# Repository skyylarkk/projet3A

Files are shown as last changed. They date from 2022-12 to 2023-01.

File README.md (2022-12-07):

# Robot arm project

This project is carried out by a three-students group in option Mechatronics and Complex Systems at ENSEA.

### Objectives

Our project consists in the realization of a 6-axis robot capable of catching and maintaining without damaging it a pot of yogurt. This could help people with disabilities.

### Mecanics

The mechanical part of the robot is modelled using SolidWorks software and then printed in 3D. The corresponding folder in the repository lists the various elements of the robot and their associated SolidWorks files (parts + assembly).

### Power module

In order to make the robot work, we need to build a power module to distribute the right power to every parts of the robot. The robot is powered by alternative by 230 V at 50 Hz.

### Steppers code

We chose to command the steppers with a STM32 nucleo-G431RB card. We use the STM32CubeIDE software. The different code files for the command of these steppers are present in the corresponding folder in the repository.

## To start

Here are the different instructions instructions instructions to follow to make the project work :

### Requirements

In order to make the project work, you will need the following softwares :

- STM32CubeIDE
- SolidWorks
- a software to print in 3D
- a software for PCB modeling

You also need this equipement to build your robot :

- a 3D-printer
- a STM32 Nucleo-G431RB
- 3x stepper motors with at least a 4N tork 
- 2x AX-12
- 2x XL-320
- a power conversion module from 230 V to 24 V
- all the componants to make the PCB (you can see them in the PCB files)

## Starting

In the different folders of the repository you have access to the code for the steppers, the mecanical parts and the PCB scheme for the power module of the robot.

- for the steppers code, you need to use STM32CubeIDE to upload the code on your Nucleo. Be careful to use the code from the last stable version for this project.
- for the mecanical parts, you have acces to the files you can open with SolidWorks. It is useful if you want to modify the different part ase you want, but it can possibly impact the proper functioning of the robot. You also have access to STL files of every mecanical parts in order to print it in 3D.
- for the PCB, you have all the files needed to build it in order to make the robot work.

## Built/developped with

* [STM32CubeIDE](https://www.st.com/en/development-tools/stm32cubeide.html) - for the steppers code
* [SolidWorks](https://www.solidworks.com/) - for the mecanical parts

## Versions

**Last stable version :** 1.0
**Last version :** 1.0

## Autors

* **CHAPUIS Clément** _alias_ [@ClementChapuis](https://github.com/ClementChapuis)
* **HERAULT Félix** _alias_ [@FelixHerault](https://github.com/FelixHerault)
* **SUTRA Aurélien** _alias_ [@skyylarkk](https://github.com/skyylarkk)

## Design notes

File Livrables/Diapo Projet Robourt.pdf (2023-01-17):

# Réalisation d’un robot d’assistance pour les personnes en situation de handicap

## École Nationale Supérieure de l’Électronique et de ses Applications, Option Mécatronique et Systèmes Complexes

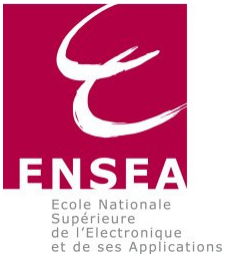
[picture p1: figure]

### Professeurs encadrants : Alexis MARTIN Nicolas PAPAZOGLOU

Année 2022 - 2023

Clément CHAPUIS, Félix HERAULT et Aurélien SUTRA Option MSC
Soutenance de projet

### 11 Janvier 2023

# Sommaire

### I - Contexte, objectifs et organisation du Projet 1 Contexte et objectifs 2 Diagramme de Gantt

### II - Le projet 1 Dimensionnement 2 Modélisation 3 Modèle réel 4 Commande des steppers

III - Conclusion | 2

3

# Contexte du projet

Contexte | Projet | Conclusion

Robot d'assistance

Mise en situation : préhension d'un pot de yaourt

Partenariat avec une clinique

Partage du travail avec un groupe d'étudiant en deuxième année

4

# Objectifs

Manipulation du pot de yaourt sans détérioration

Maintient de la position pendant l'alimentation du patient

Commande au fauteuil

Mémorisation de la position ?

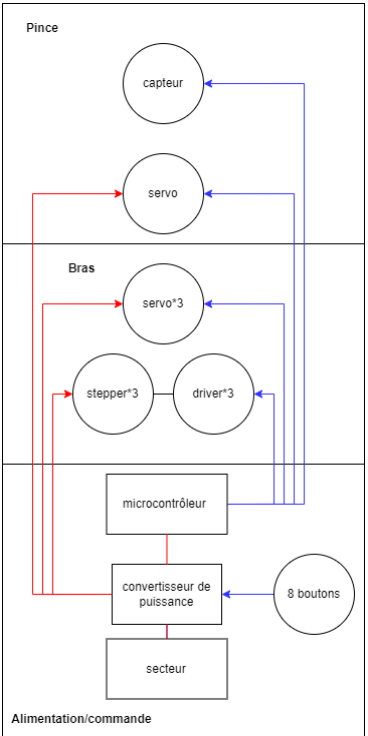
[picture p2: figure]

5

# Solution retenue

Robot 6 axes anthropomorphe avec différents modèles de pinces

Réduit à 3 axes avec une pince simple au fil du projet

# Digramme de Gantt

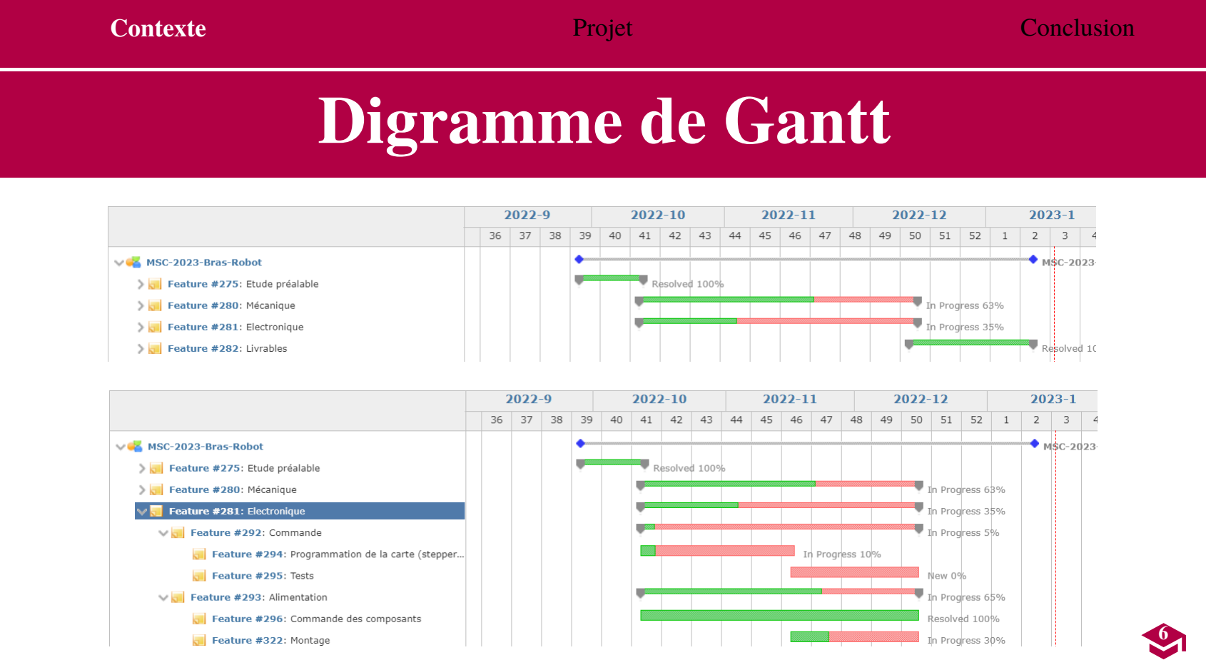
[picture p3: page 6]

6

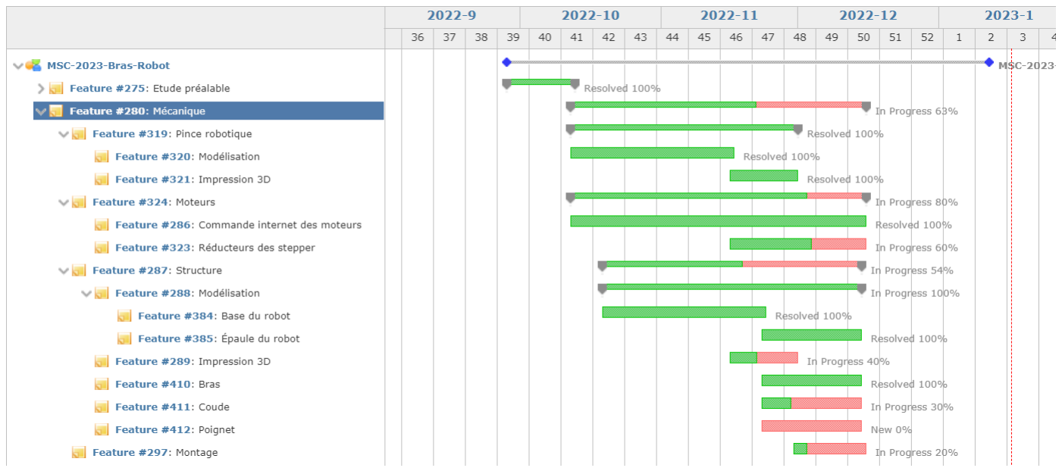
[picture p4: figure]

7

# Digramme de Gantt

# Architecture générale

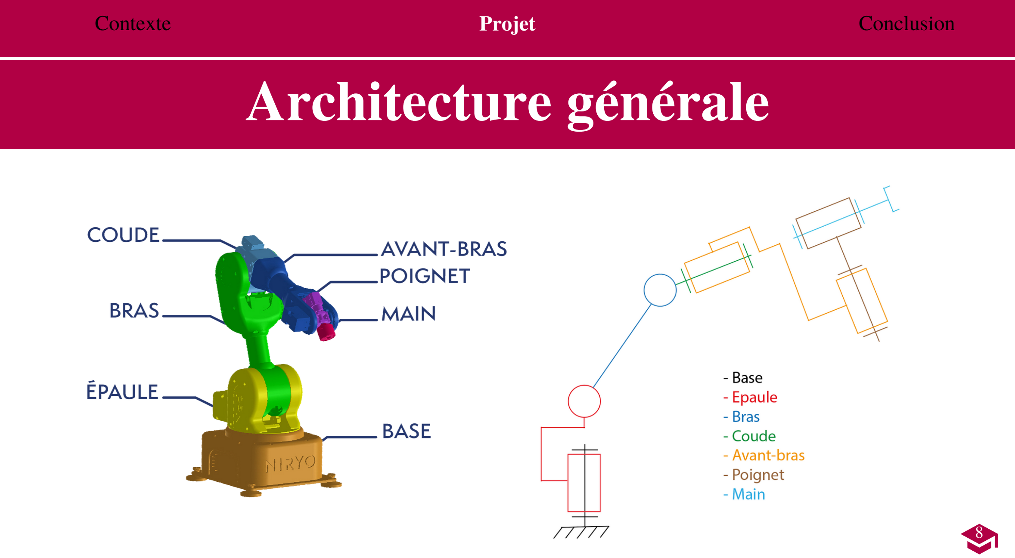
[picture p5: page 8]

8

# Dimensionnement

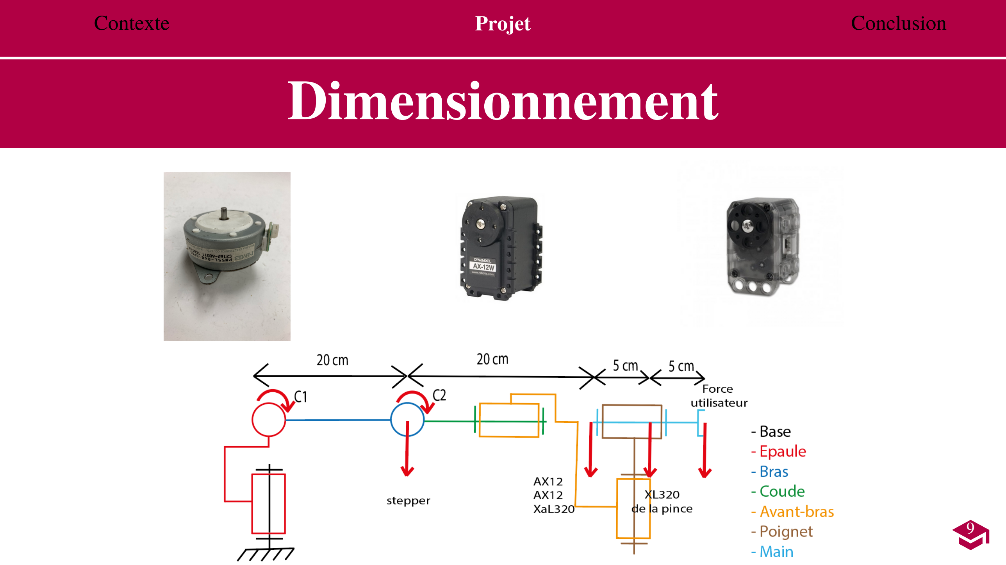
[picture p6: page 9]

9

# Modélisation - Base

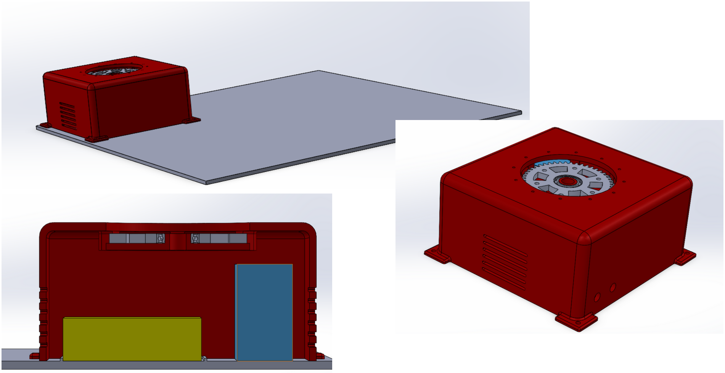
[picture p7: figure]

10

# Modélisation - Base

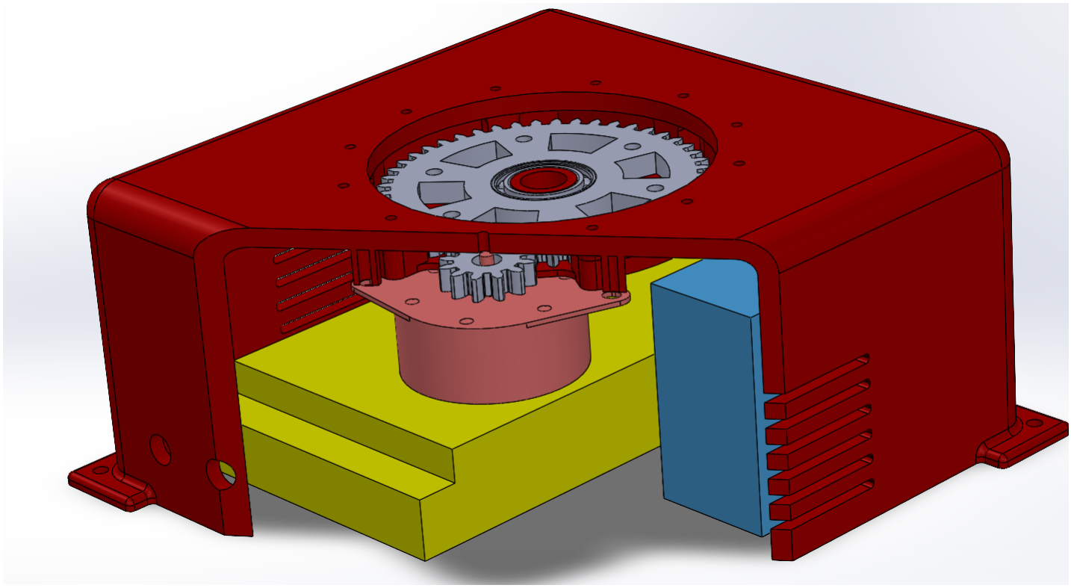
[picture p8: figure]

11

# Modélisation - Epaule

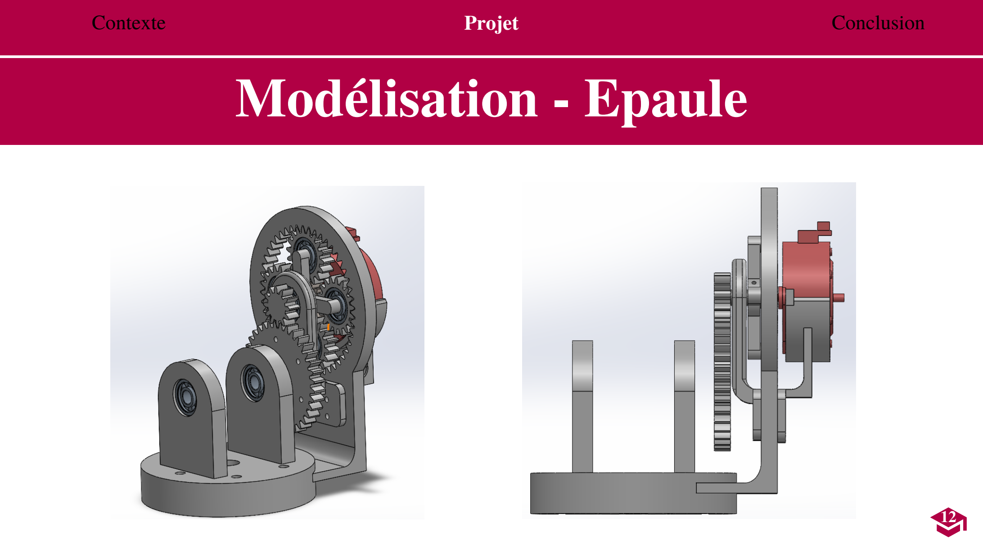
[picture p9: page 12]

12

# Modélisation - Epaule

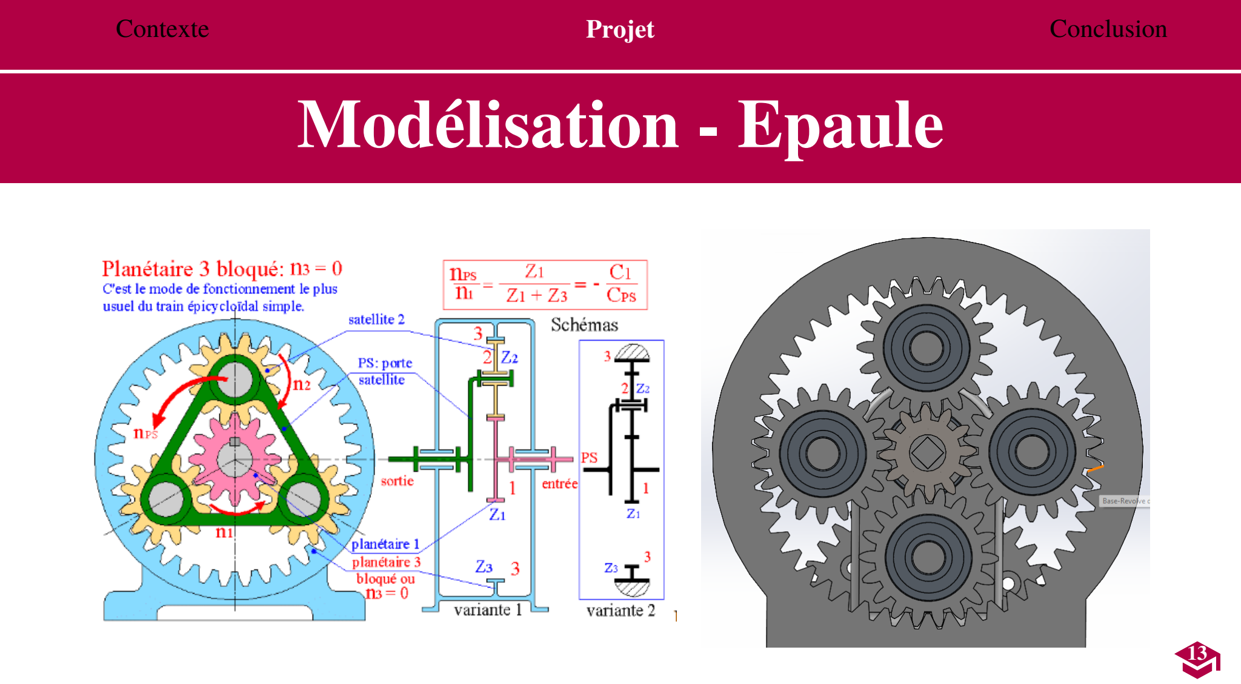
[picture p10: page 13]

13

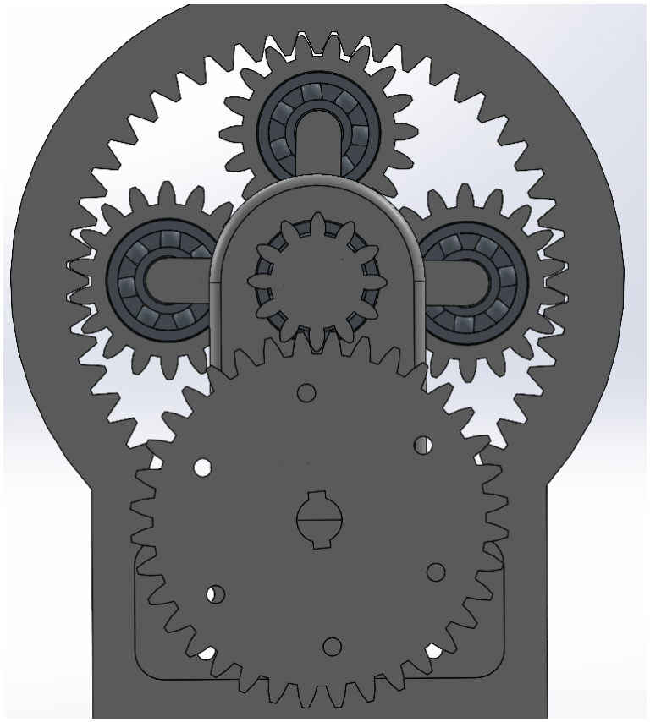
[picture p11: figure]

14

# Modélisation - Epaule

# Modélisation - Epaule + Bras

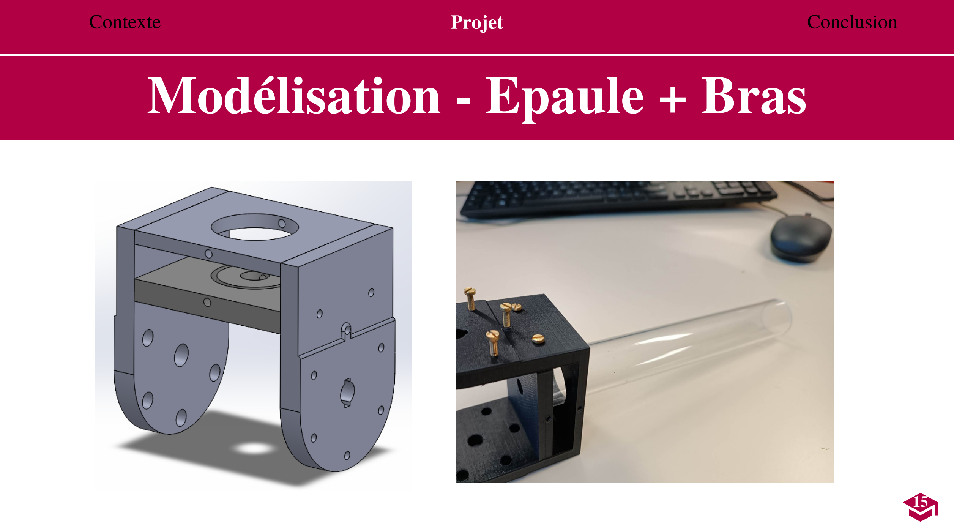
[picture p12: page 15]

15

# Modélisation

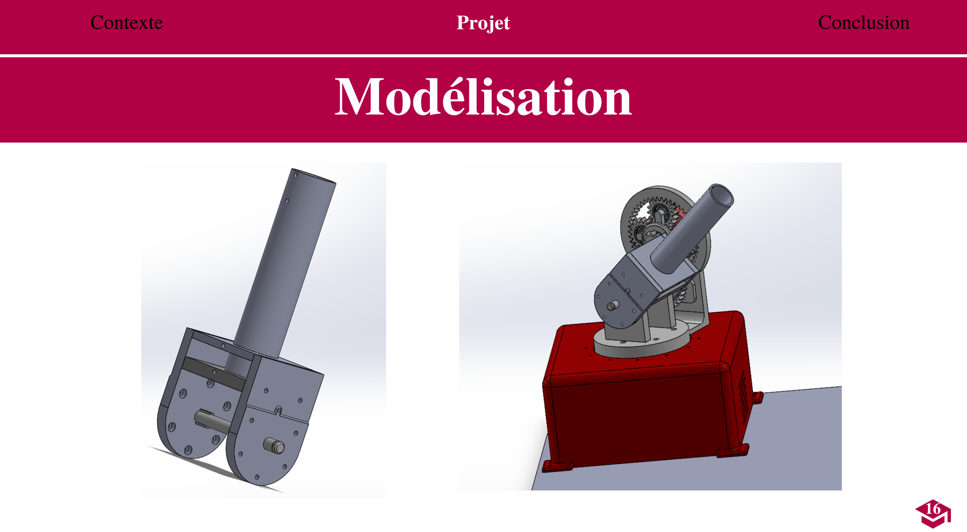
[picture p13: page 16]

16

# Modélisation - Pince

17

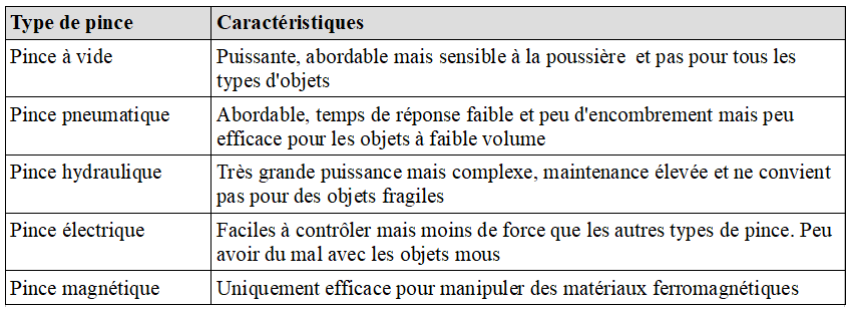
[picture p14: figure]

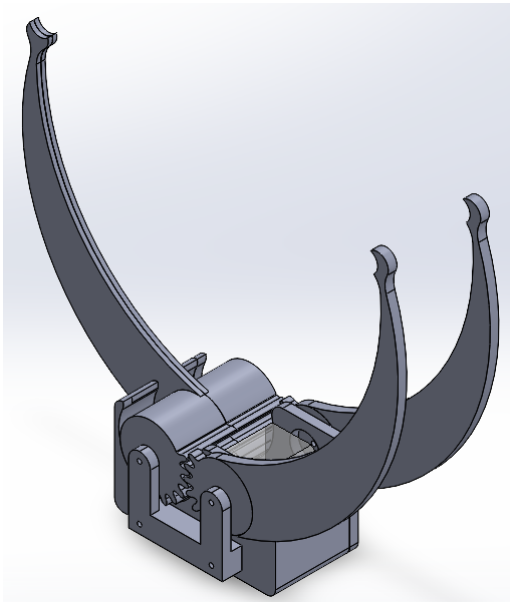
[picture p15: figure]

18

# Modélisation - Pince

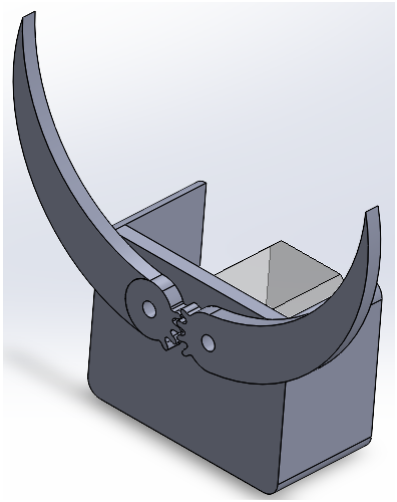
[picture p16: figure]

# Modèle réel

# Place à la démonstration

19

# Commande des steppers

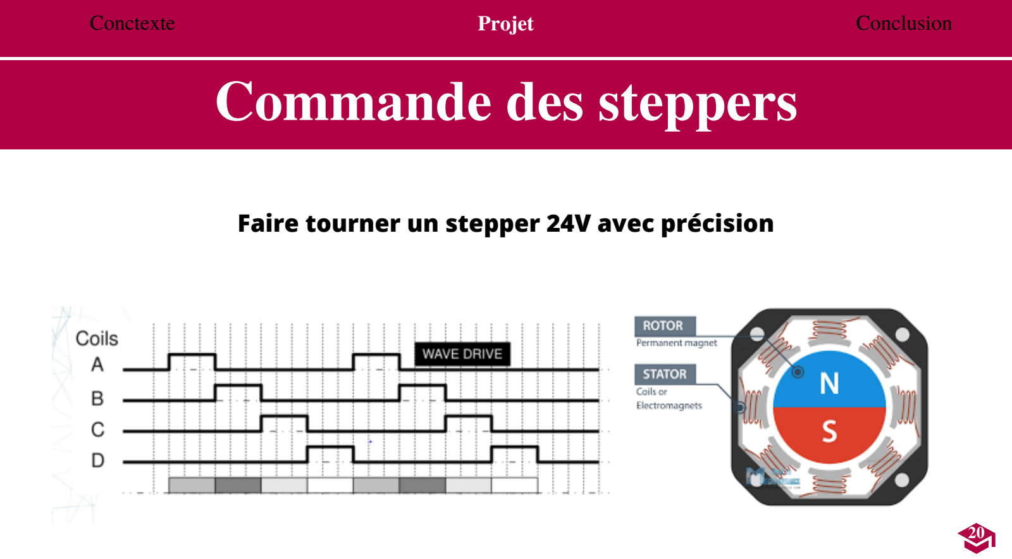
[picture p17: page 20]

Conctexte | Projet | Conclusion

Faire tourner un stepper 24V avec précision

20

# Commande des steppers

Conctexte | Projet | Conclusion

Solution : microstepping avec le driver TMC2225

4, 8, 16 ou 32 microsteps

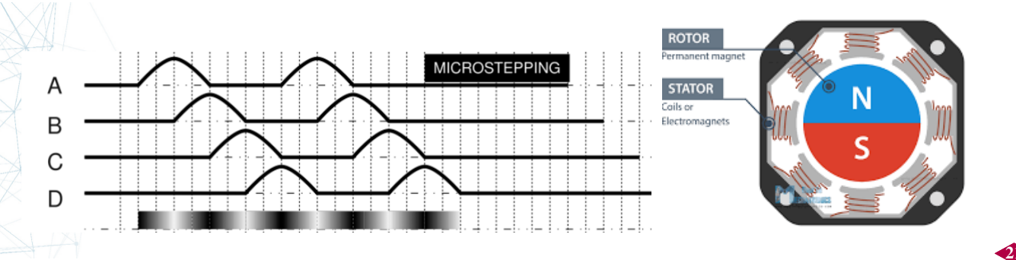
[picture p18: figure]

21

# TMC2225

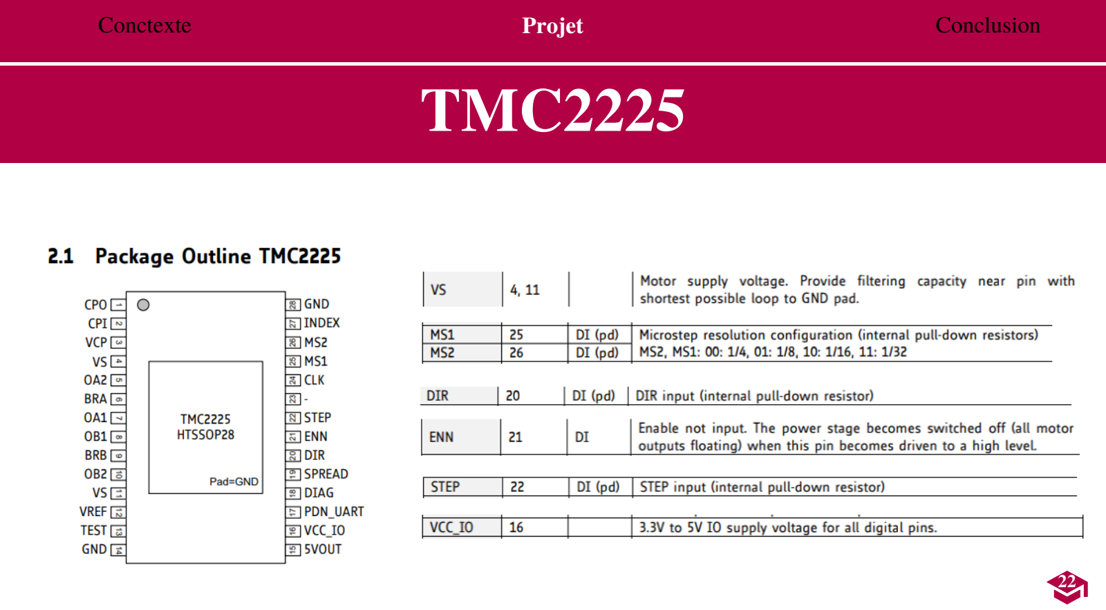
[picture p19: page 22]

Conctexte | Projet | Conclusion

22

# Buck

Conctexte | Projet | Conclusion

Convertit le 24V en 5V

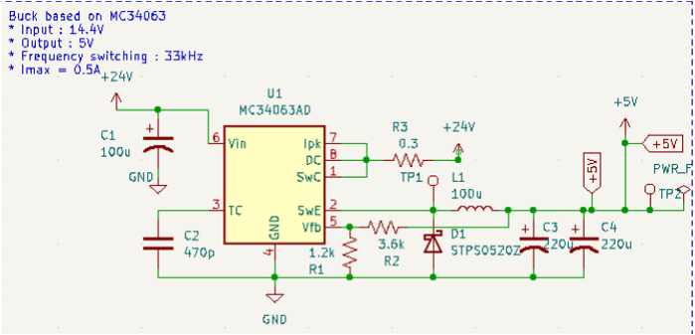
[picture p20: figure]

23

# Liaison entre les composants

Conctexte | Projet | Conclusion

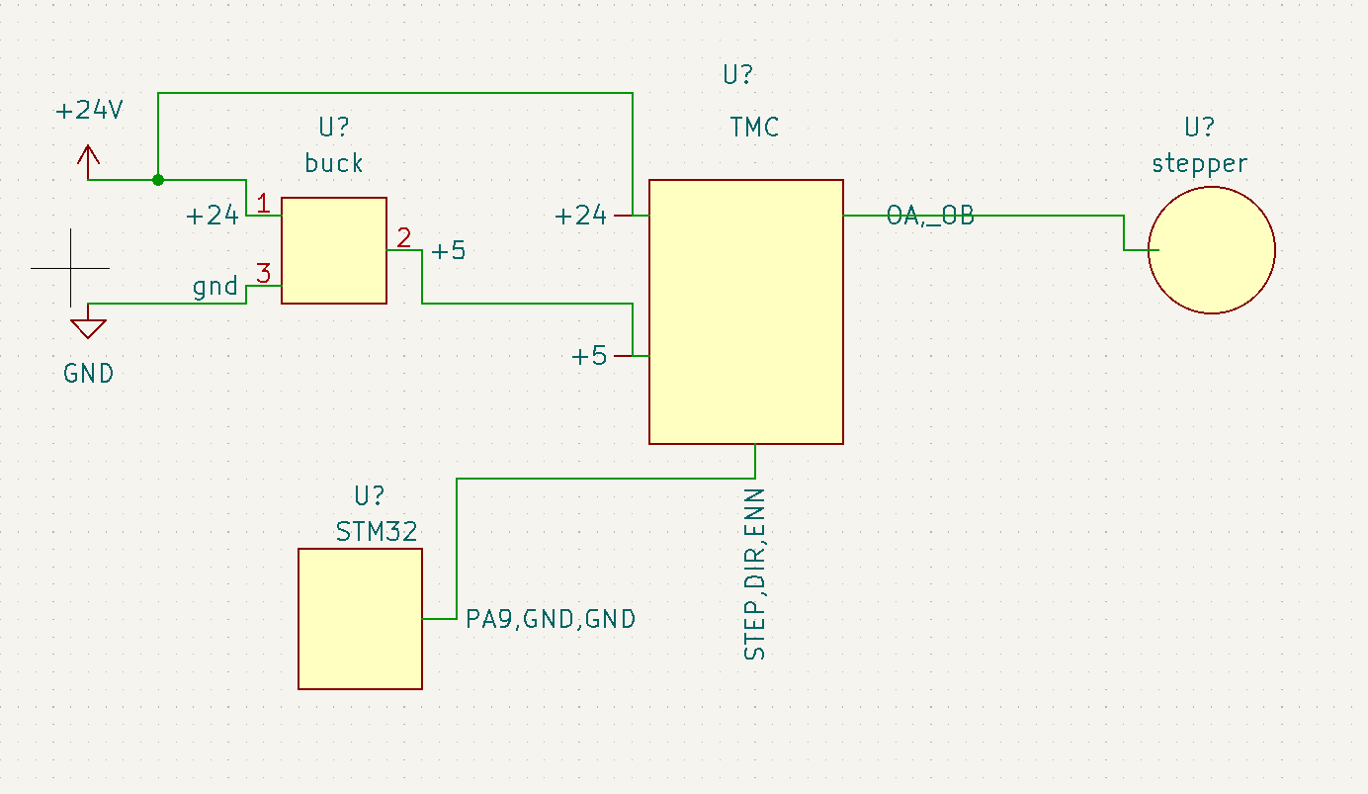
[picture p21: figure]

24

# Création du PCB

Conctexte | Projet | Conclusion

25

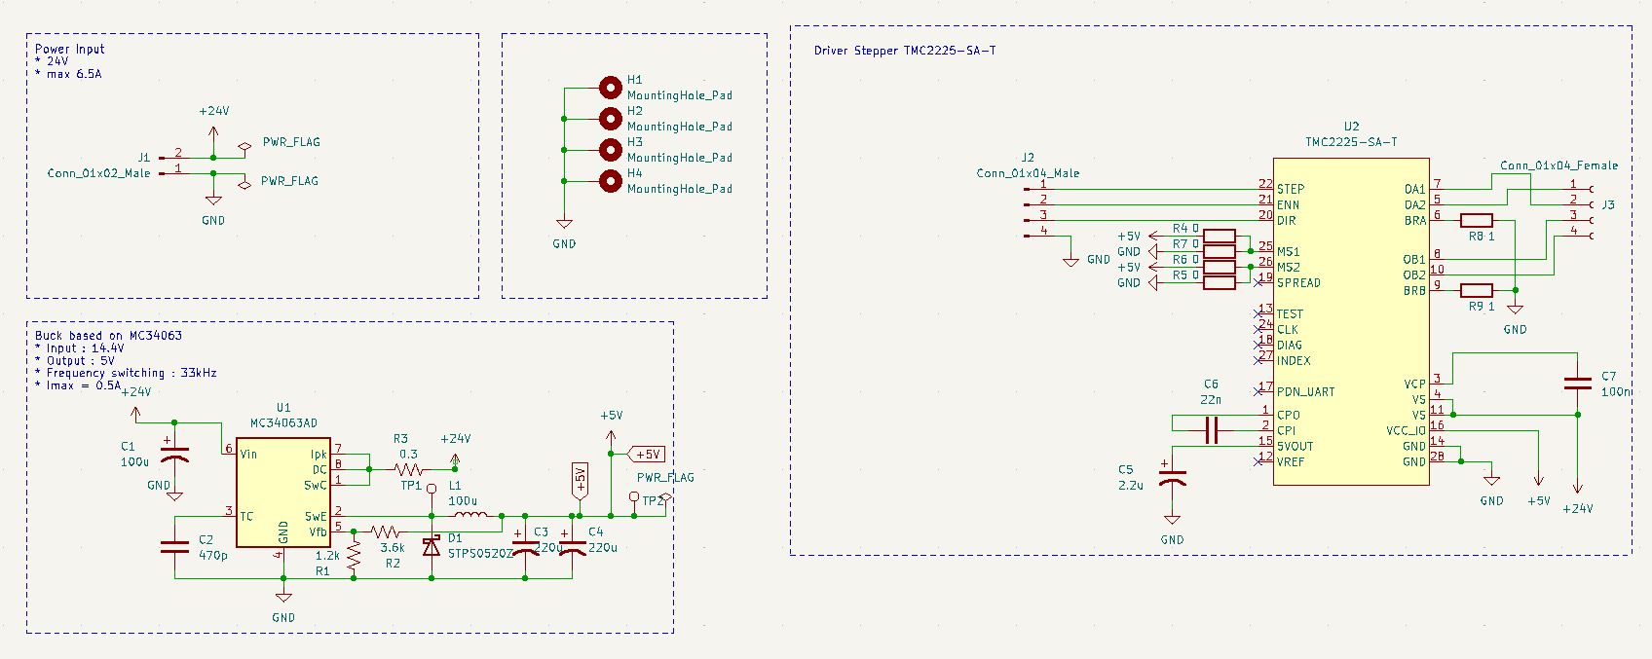
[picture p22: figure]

# Création du PCB

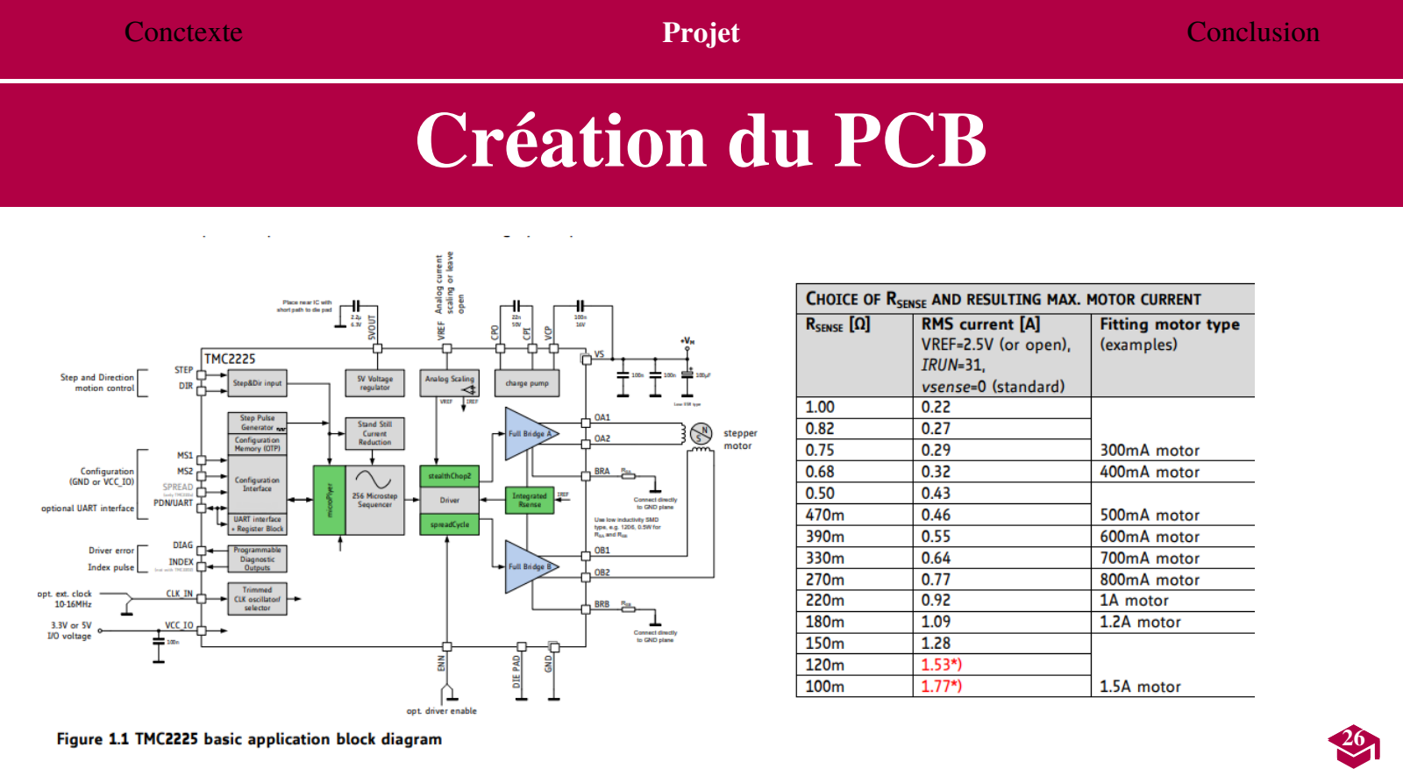
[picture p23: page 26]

Conctexte | Projet | Conclusion

26

# Modèle final

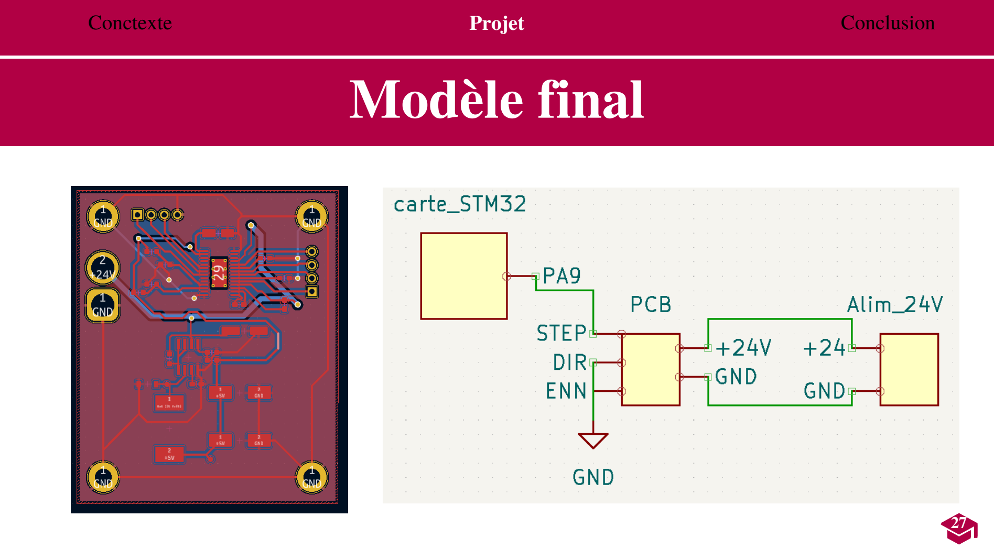
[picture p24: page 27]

Conctexte | Projet | Conclusion

27

# Résultats de la commande des steppers

Conctexte | Projet | Conclusion

La partie alimentation fonctionne correctement

Le driver ne réagit pas aux PWM

28

# Conclusion

Robot réel non terminé

Pas de stepper fonctionnels

Beaucoup de problèmes à
surmonter

Beaucoup d'apprentissage
technique

Développement de
compétences humaines

Beaucoup de plaisir !

29

# Nous vous remercions pour votre attention

# Nous sommes à votre disposition pour répondre à vos questions

30

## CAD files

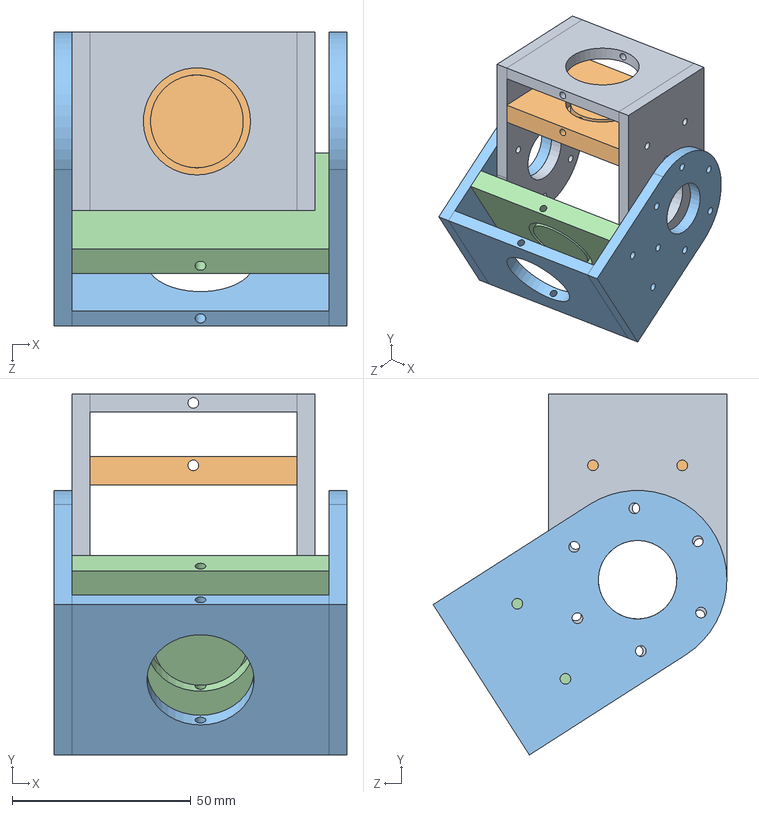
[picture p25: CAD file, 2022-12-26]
Modele_Solidworks/Avant-bras/Assemblage_complet.SLDASM
82.0 x 101.1 x 82.3 mm
Carcasse_av_bras
Support_axe_2
Carcasse_bras
Support_axe

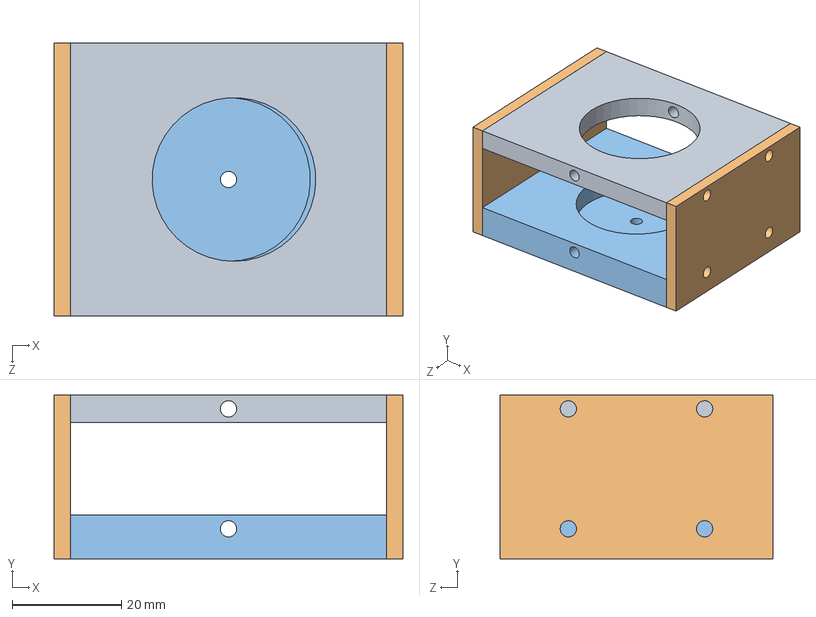
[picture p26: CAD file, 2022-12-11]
Modele_Solidworks/Poignet/Assemblage1.SLDASM
64.0 x 30.0 x 50.0 mm
Carcasse - Copie
Côté_1_ext - Copie x 2
Support_axe_2

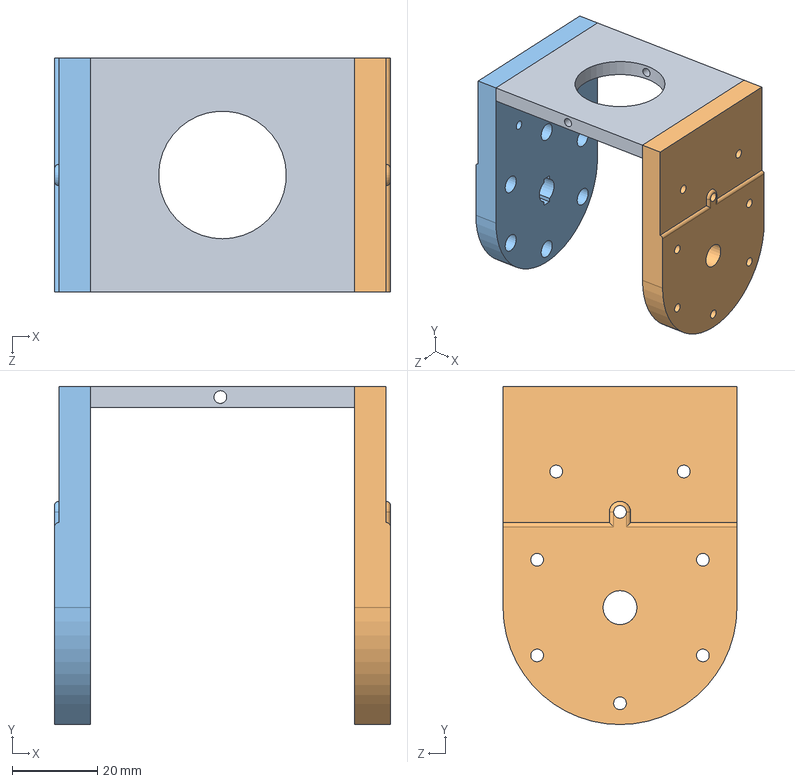
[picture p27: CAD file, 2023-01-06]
Modele_Solidworks/Bras/Carcasse_bras.SLDASM
79.0 x 79.5 x 55.0 mm
Carcasse
Côté_ext
Côté_ext - Copie

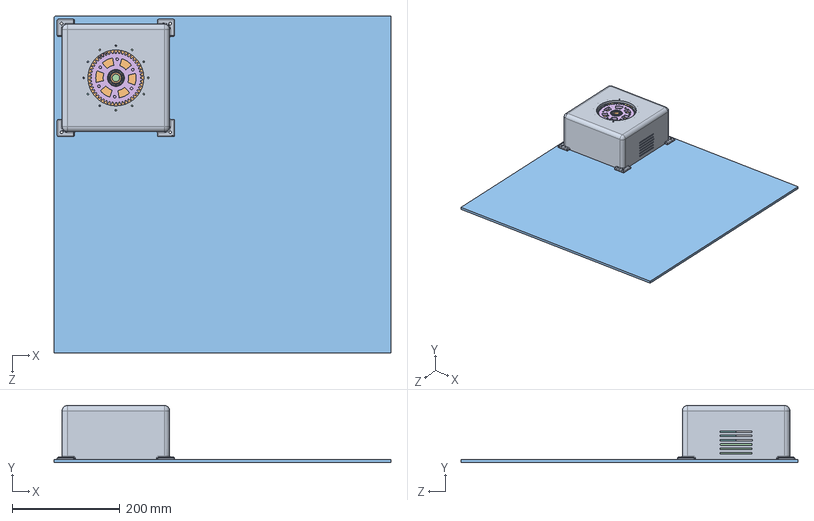
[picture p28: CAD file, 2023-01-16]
Modele_Solidworks/Base/assemblage bati en 2 piece.SLDASM
626.0 x 106.0 x 626.0 mm
block bati 1v2
block bati 2v2
plateau
transfo
roue sur pignon moteur
grande roue pour epaule
PM55L-048
carte
bearing_61804_2_01
bearing_61804_2_02
bearing_61804_2_03

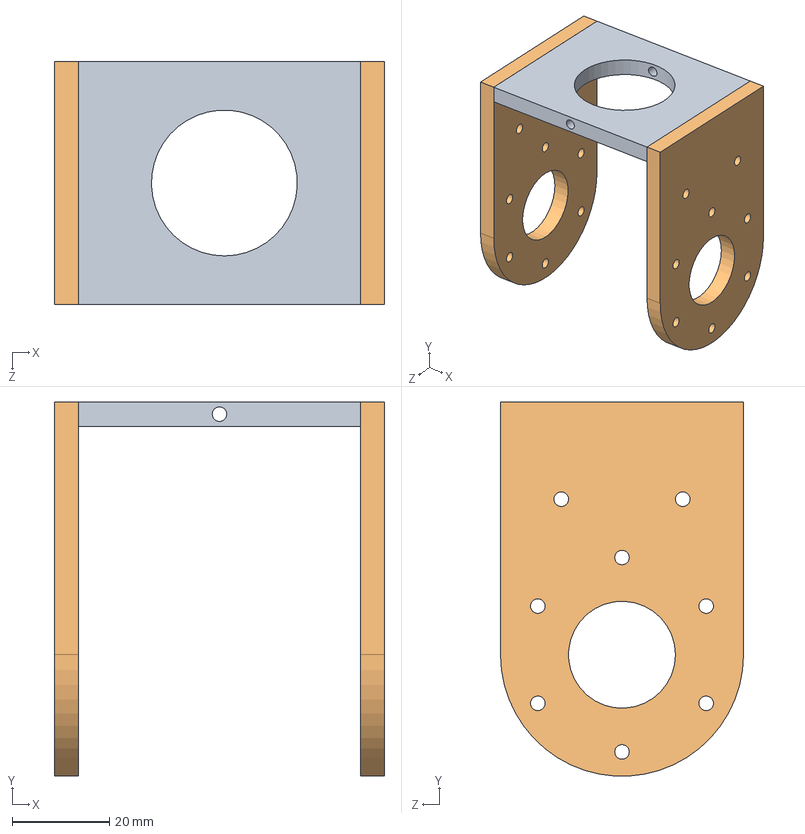
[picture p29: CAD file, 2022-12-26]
Modele_Solidworks/Avant-bras/Carcasse_av_bras.SLDASM
68.0 x 77.0 x 50.0 mm
Carcasse - Copie
Côté_ext x 2

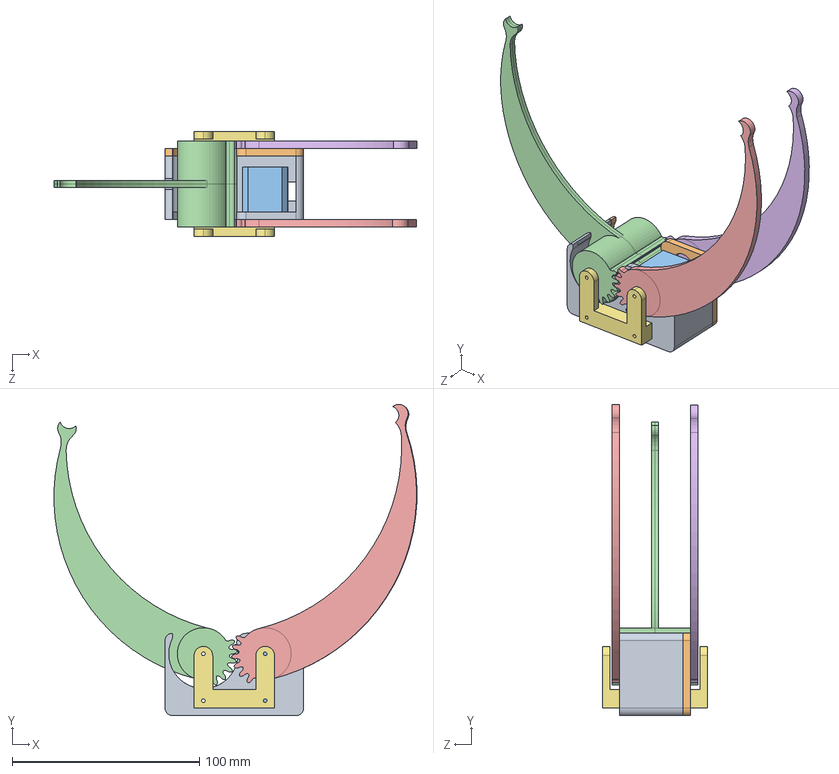
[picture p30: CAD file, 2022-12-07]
Modele_Solidworks/Pince/Assemblage.SLDASM
193.8 x 166.2 x 56.0 mm
Base
Base - Copie
XL-320
Pièce1 - Copie (2)
Pièce1
Pièce1 - Copie
Bloqueur x 2

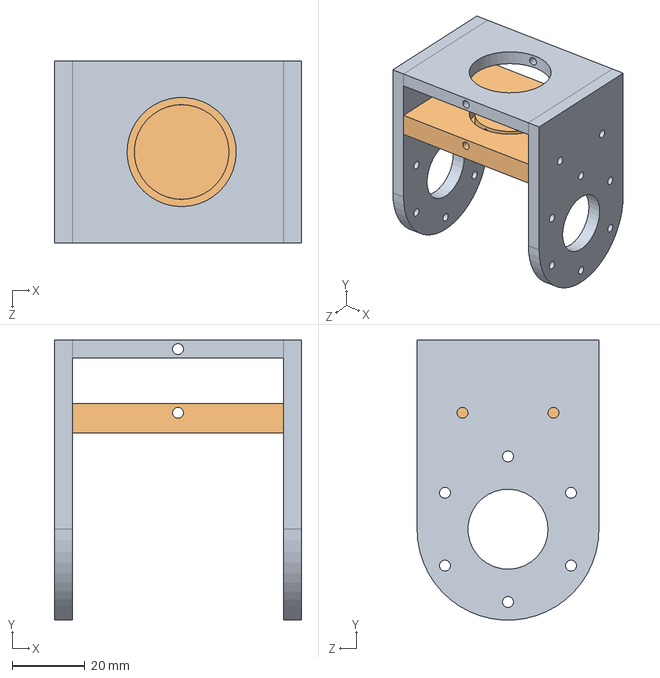
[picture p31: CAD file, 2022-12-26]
Modele_Solidworks/Avant-bras/Assemblage_av_bras.SLDASM
68.0 x 77.0 x 50.0 mm
Carcasse_av_bras
Support_axe_2

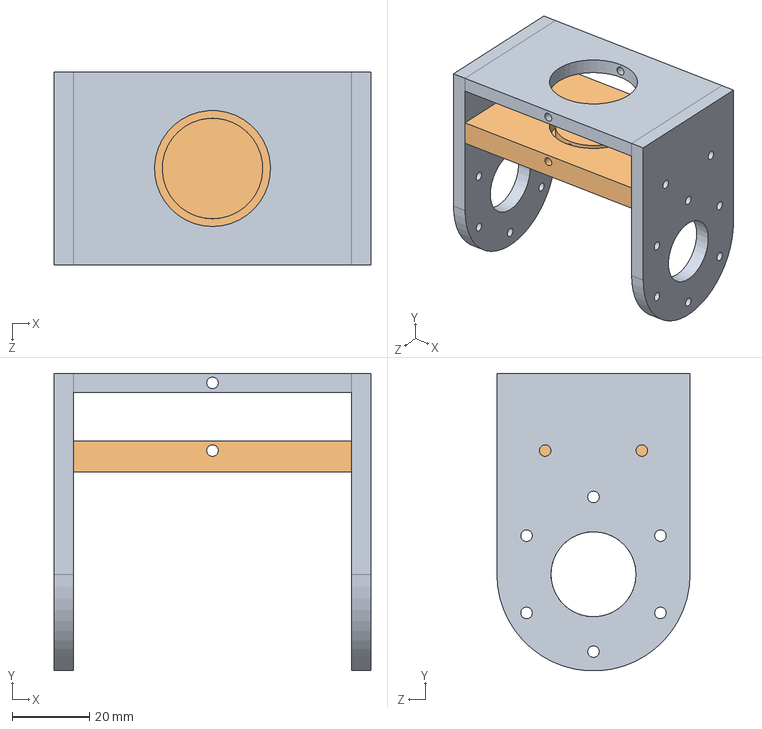
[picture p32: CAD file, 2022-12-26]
Modele_Solidworks/Avant-bras/Assemblage_bras.SLDASM
82.0 x 77.0 x 50.0 mm
Carcasse_bras
Support_axe

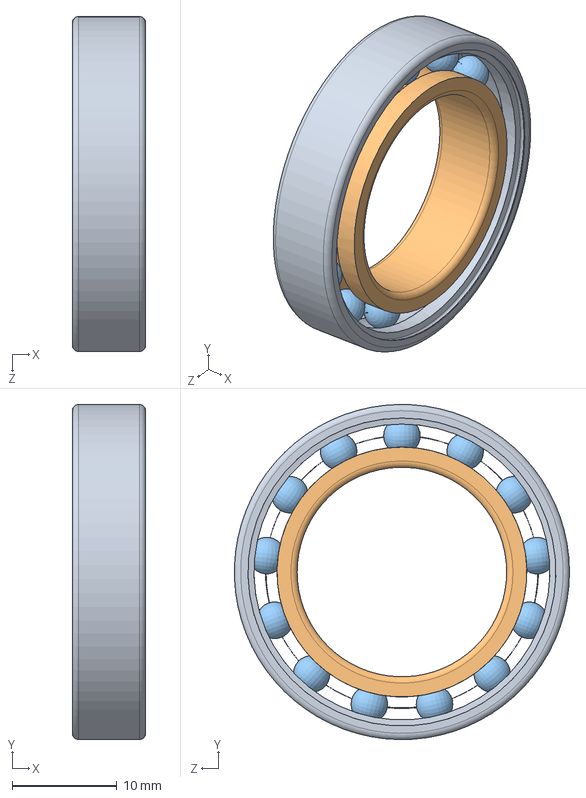
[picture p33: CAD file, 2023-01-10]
Modele_Solidworks/Base/bearing_61804_2.SLDASM
7.00 x 32.0 x 32.0 mm
bearing_61804_2_01
bearing_61804_2_02
bearing_61804_2_03

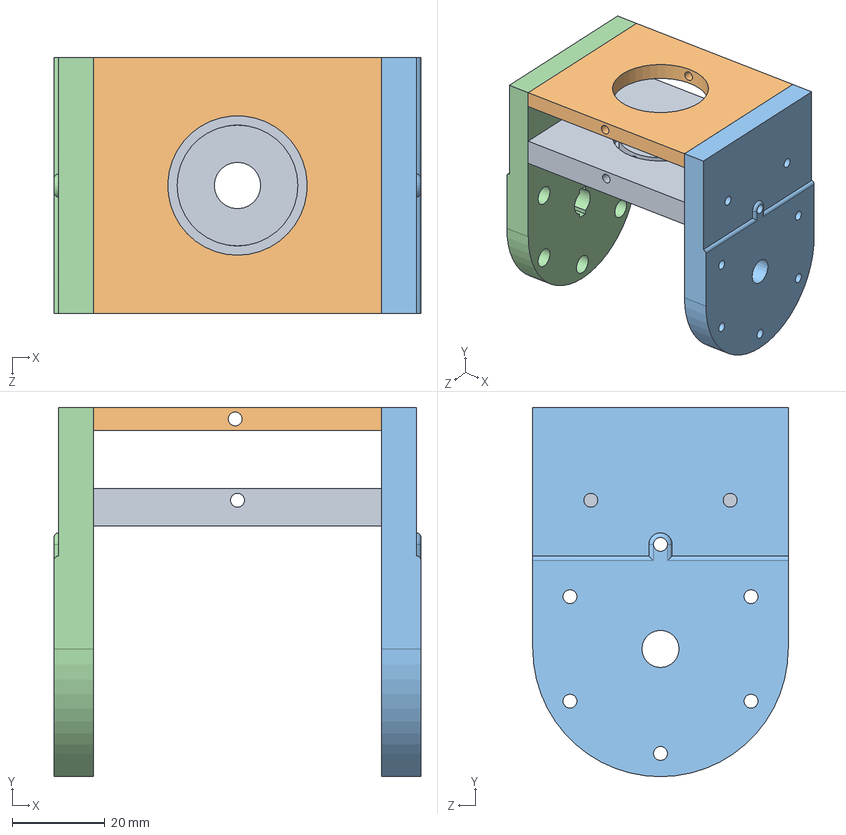
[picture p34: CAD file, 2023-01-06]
Modele_Solidworks/Bras/Assemblage_bras.SLDASM
79.0 x 79.5 x 55.0 mm
Support_axe
Carcasse
Côté_ext
Côté_ext - Copie

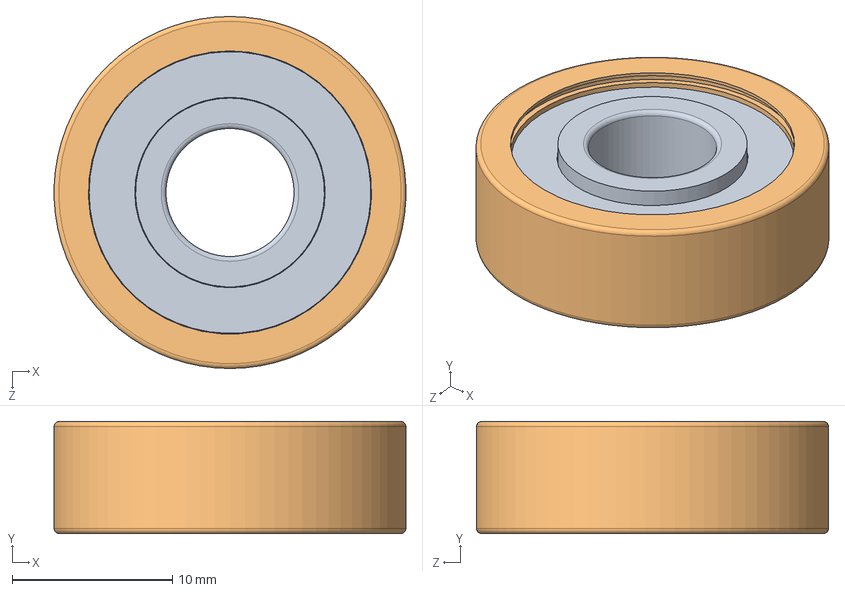
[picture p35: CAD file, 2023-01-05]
Modele_Solidworks/Epaule/roulement/608.SLDASM
22.0 x 7.00 x 22.0 mm

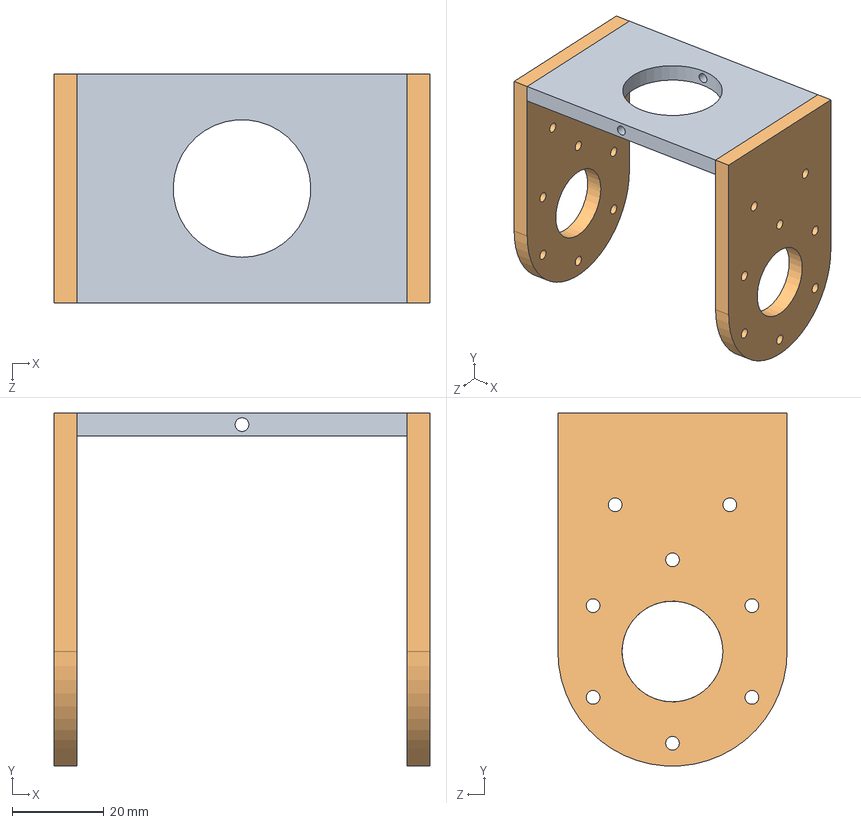
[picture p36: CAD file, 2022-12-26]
Modele_Solidworks/Avant-bras/Carcasse_bras.SLDASM
82.0 x 77.0 x 50.0 mm
Carcasse
Côté_ext x 2

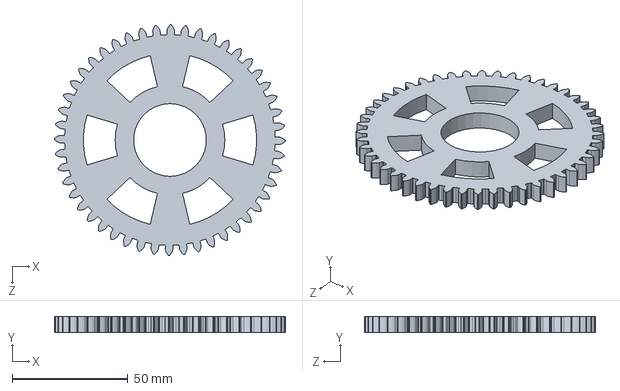
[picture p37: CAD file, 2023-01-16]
Modele_Solidworks/Base/grande roue pour epaule.SLDPRT
100.0 x 7.00 x 100.0 mm

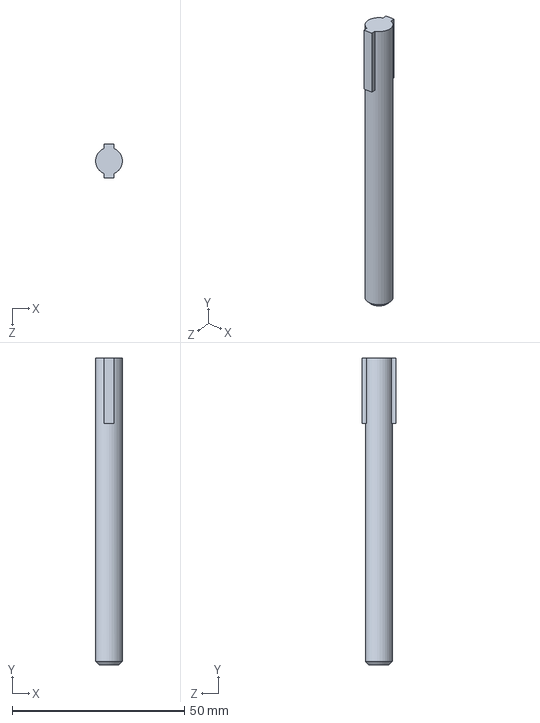
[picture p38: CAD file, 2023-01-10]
Modele_Solidworks/Bras/axe.SLDPRT
7.79 x 89.0 x 10.0 mm

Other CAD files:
Modele_Solidworks/Epaule/bearing_61804_2.SLDASM
Modele_Solidworks/Epaule/roulement/608_06.SLDPRT
Modele_Solidworks/Pince/Pièce1.SLDPRT
Modele_Solidworks/Avant-bras/Carcasse - Copie.SLDPRT
Modele_Solidworks/Avant-bras/Carcasse.SLDPRT
Modele_Solidworks/Avant-bras/Carcasse_av_bras.SLDPRT
Modele_Solidworks/Avant-bras/Carcasse_bras.SLDPRT
Modele_Solidworks/Avant-bras/Côté_ext.SLDPRT
Modele_Solidworks/Avant-bras/Support_axe.SLDPRT
Modele_Solidworks/Avant-bras/Support_axe_2.SLDPRT
Modele_Solidworks/Base/base bati 2.SLDPRT
Modele_Solidworks/Base/base bati1.SLDPRT
Modele_Solidworks/Base/bearing_61804_2_01.SLDPRT
Modele_Solidworks/Base/bearing_61804_2_02.SLDPRT
Modele_Solidworks/Base/bearing_61804_2_03.SLDPRT
Modele_Solidworks/Base/carte.SLDPRT
Modele_Solidworks/Base/plateau.SLDPRT
Modele_Solidworks/Base/roue sur pignon moteur.SLDPRT
Modele_Solidworks/Base/transfo.SLDPRT
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

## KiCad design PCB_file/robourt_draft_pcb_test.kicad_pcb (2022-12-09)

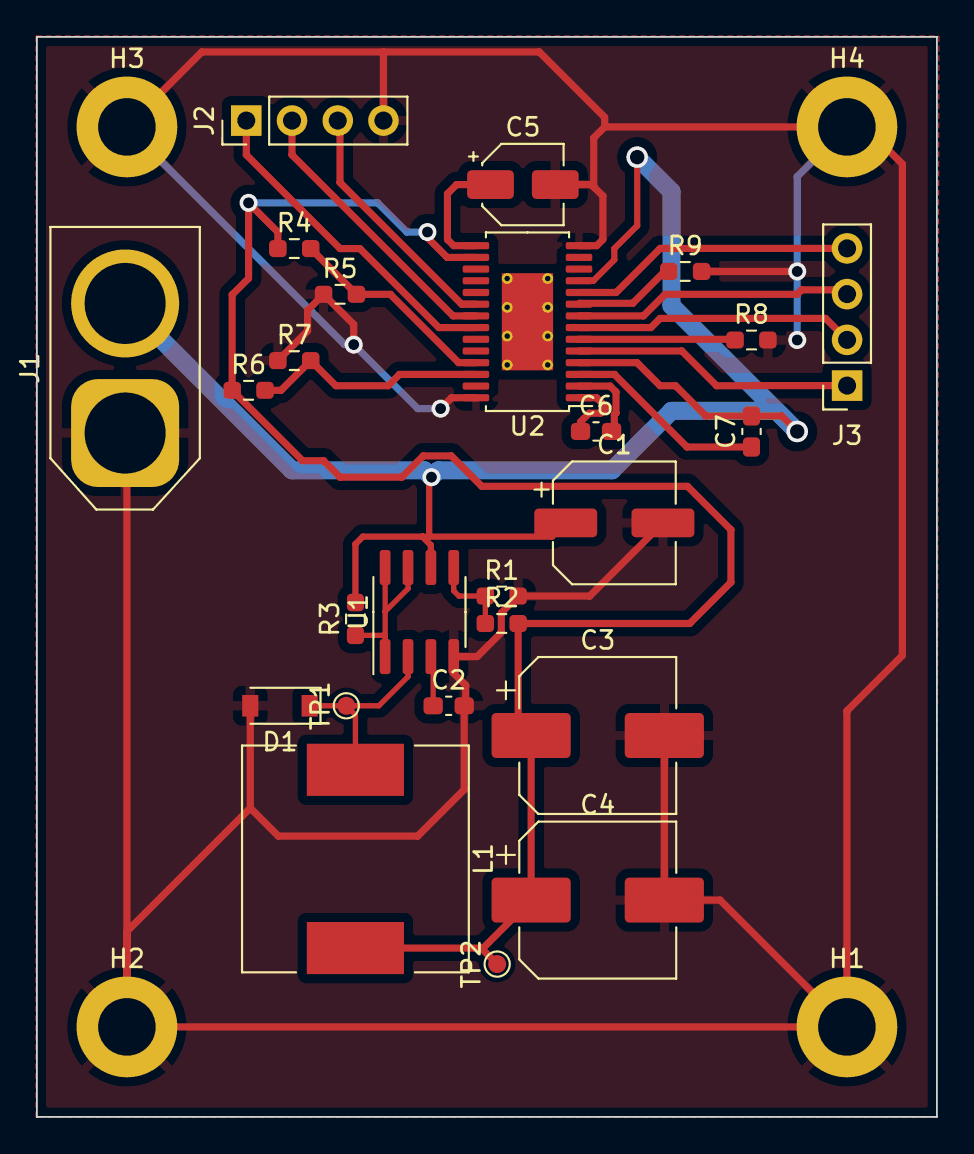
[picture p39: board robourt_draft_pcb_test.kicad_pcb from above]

Board: 2 copper layers, 50.0 x 60.0 mm, 29 parts (0 on the bottom side), 22 nets.

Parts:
C1: 100u; CP_Elec_6.3x7.7
C2: 470p; C_0603_1608Metric_Pad1.08x0.95mm_HandSolder
C3, C4: 220u; CP_Elec_8x10.5
C5: 2.2u; CP_Elec_4x5.7
C6: 22n; C_0603_1608Metric_Pad1.08x0.95mm_HandSolder
C7: 100n; C_0603_1608Metric_Pad1.08x0.95mm_HandSolder
D1: STPS0520Z; D_SOD-123
H1, H2, H3, H4: MountingHole_Pad; MountingHole_3.2mm_M3_DIN965_Pad
J1: Conn_01x02_Male; AMASS_XT60-M_1x02_P7.20mm_Vertical
J2: Conn_01x04_Male; PinHeader_1x04_P2.54mm_Vertical
J3: Conn_01x04_Female; PinSocket_1x04_P2.54mm_Vertical
L1: 100u; L_12x12mm_H6mm
R1: 1.2k; R_0603_1608Metric_Pad0.98x0.95mm_HandSolder
R2: 3.6k; R_0603_1608Metric_Pad0.98x0.95mm_HandSolder
R3: 0.3; R_0603_1608Metric_Pad0.98x0.95mm_HandSolder
R4, R5, R6, R7: 0; R_0603_1608Metric_Pad0.98x0.95mm_HandSolder
R8, R9: 1; R_0603_1608Metric_Pad0.98x0.95mm_HandSolder
TP1: BUCK_OUT; TestPoint_Pad_D1.0mm
TP2: +5V; TestPoint_Pad_D1.0mm
U1: MC34063AD; SOIC-8_3.9x4.9mm_P1.27mm
U2: TMC2225-SA-T; HTSSOP-28-1EP_4.4x9.7mm_P0.65mm_EP2.85x5.4mm_ThermalVias

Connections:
+5V: C3.1, C4.1, L1.2, R2.2, R4.1, R6.1, TP2.1, U2.16 (VCC_IO)
+24V: C1.1, C7.2, J1.2, R3.2, U1.6 (Vin), U2.4 (VS), U2.11 (VS)
GND: C1.2, C2.2, C3.2, C4.2, C5.2, D1.2 (A), H1.1, H2.1, H3.1, H4.1, J1.1, J2.4, R1.2, R5.1, R7.1, R8.2, R9.2, U1.4 (GND), U2.14 (GND), U2.28 (GND)
unnamed: C2.1, U1.3 (TC)
unnamed: C6.1, U2.1 (CPO)
unnamed: C6.2, U2.2 (CPI)
unnamed: C7.1, U2.3 (VCP)
unnamed: D1.1 (K), L1.1, TP1.1, U1.2 (SwE)
unnamed: J2.1, U2.22 (STEP)
unnamed: J2.2, U2.21 (ENN)
unnamed: J2.3, U2.20 (DIR)
unnamed: J3.3, U2.8 (OB1)
unnamed: J3.4, U2.10 (OB2)
unnamed: R1.1, R2.1, U1.5 (Vfb)
unnamed: R3.1, U1.1 (SwC), U1.7 (Ipk), U1.8 (DC)
unnamed: R4.2, R5.2, U2.25 (MS1)
unnamed: R6.2, R7.2, U2.26 (MS2)
unnamed: R8.1, U2.6 (BRA)
unnamed: R9.1, U2.9 (BRB)
unnamed: J3.1, U2.5 (OA2)
unnamed: J3.2, U2.7 (OA1)
unnamed: C5.1, U2.15 (5VOUT)

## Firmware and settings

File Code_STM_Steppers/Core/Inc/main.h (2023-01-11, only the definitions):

#define B1_Pin GPIO_PIN_13
#define B1_GPIO_Port GPIOC
#define LPUART1_TX_Pin GPIO_PIN_2
#define LPUART1_TX_GPIO_Port GPIOA
#define LPUART1_RX_Pin GPIO_PIN_3
#define LPUART1_RX_GPIO_Port GPIOA
#define LD2_Pin GPIO_PIN_5
#define LD2_GPIO_Port GPIOA
#define T_SWDIO_Pin GPIO_PIN_13
#define T_SWDIO_GPIO_Port GPIOA
#define T_SWCLK_Pin GPIO_PIN_14
#define T_SWCLK_GPIO_Port GPIOA
#define T_SWO_Pin GPIO_PIN_3
#define T_SWO_GPIO_Port GPIOB

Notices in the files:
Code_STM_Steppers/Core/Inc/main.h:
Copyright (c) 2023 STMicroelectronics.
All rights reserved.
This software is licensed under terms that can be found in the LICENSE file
